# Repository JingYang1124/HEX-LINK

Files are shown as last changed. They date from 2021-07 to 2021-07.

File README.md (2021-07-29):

# HEX LINK - *A Distributed Somatosensory Interaction Device*  

#### 

#### 介绍
**HEX LINK**: **H**igher-order **EX**cess **LINK**

**这是一套可适用于PC端游戏的体感操作设备。**

Hex_Link+4

项目演示视频链接：  

[【开源·自制】真正的体感"只狼"_哔哩哔哩_bilibili](https://www.bilibili.com/video/BV1qy4y1M7Zw)

[【自制】"真 · 脚动档"极品飞车--程序员的健身日常_哔哩哔哩_bilibili](https://www.bilibili.com/video/BV1m54y1L7WU)

本仓库文件夹结构： 

```hxml
.
├─firmware # 软件（根据自己使用的工具选择如下一种工程即可）
│  ├─ArduinoIDE_Proj # Arduino IDE版工程 
│  │  ├─Additional_Libraries # 里面的文件夹需要复制到Arduino IDE安装目录下的libraries文件夹
│  │  ├─Hex_Link_Leonardo # 需要下载至接收端的程序
│  │  └─Hex_Link_Nano # 需要下载至发送端的程序
│  ├─Bootloaders # 需要下载至芯片的arduino bootloader 
│  └─Vscode_PlatformIO_Proj # VScode PlatformIO版工程 
│      ├─Hex_Link_Leonardo # 需要下载至接收端的程序
│      └─Hex_Link_Nano # 需要下载至发送端的程序
├─hardware # 硬件（PCB工程）
│  ├─BOM   # PCB的物料清单，包含参考的购买链接（链接仅作参考，在其他任何店铺购买相同型号即可）
│  ├─Hex_Link_Rec # 接收端PCB工程
│  ├─Hex_Link_Trans # 发送端PCB工程
│  └─Nano_Jtag_Pin # 转接板：用来烧录Nano bootloader的Jtag口转接板
├─model # 接收端外壳3维模型
│  ├─Solidworks_Project # 2018版本Solidworks工程
│  └─STL_TAP # STL文件，可直接用于3D打印.TAP文件是顶层亚克力板的CNC加工文件
├─references # 参考文档
└─tools # 额外的脚本工具
```

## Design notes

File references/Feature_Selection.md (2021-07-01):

# 基于信息增益的特征选取  

----------
> 如果数学公式无法正常显示，请下载至本地使用Typora打开或者在Chrome上安装Mathjax插件  
## 引言

**信息熵**，是一个数学上颇为抽象的概念，在这里不妨把信息熵理解成某种特定信息的出现概率。信息量度量的是一个具体事件发生了所带来的信息，而熵则是在结果出来之前对可能产生的信息量的期望。  
##### 信息熵公式：
$$H(X)=-\sum^{\infty}_{i=1}{p(x_i)\log_2(p(x_i))}$$

## 计算举例

现假设有测量了两种动作运动过程中的X轴加速度平均值  
  
动作A的X轴加速度平均值范围为A1至A3  
动作B的X轴加速度平均值范围为A2至A4

**首先计算样本的的信息熵**  
$$ H(X)=(-\frac{20}{40}\times\log_2(\frac{20}{40}))+(-\frac{20}{40}\times\log_2(\frac{20}{40}))=1$$  

以A2与A3为分界点将A1与A4上的数据分为3段  
分别计算每一段下的X的熵:  
$$ H(X|A\in[A_1,A_2))=-1\times\log_2(1)+0=0$$  
$$ H(X|A\in[A_2,A_3))=(-\frac{10}{20}\times\log_2(\frac{10}{20}))+(-\frac{10}{20}\times\log_2(\frac{10}{20}))=1$$  
$$ H(X|A\in[A_3,A_4])=-1\times\log_2(1)+0=0$$  
**条件熵**是一个X熵对A的期望
$$ H(X|A)=\frac{10}{40}\times H(X|A\in[A_1,A_2))+\frac{20}{40}\times H(X|A\in[A_2,A_3))+\frac{10}{40}\times H(X|A\in[A_3,A_4])=0.5$$  
**信息增益：**
$$g(X|A)=H(X)-H(X|A)=0.5$$

现假设如果我们也测量了两种运动过程中的Y轴加速度平均值  
其分布如下：  
  
**信息熵**  
$$ H(X)=(-\frac{20}{40}\times\log_2(\frac{20}{40}))+(-\frac{20}{40}\times\log_2(\frac{20}{40}))=1$$  

同样以A2与A3为分界点将A1与A4上的数据分为3段  
分别计算每一段下的X的熵:  
$$ H(X|A\in[A_1,A_2))=-1\times\log_2(1)+0=0$$  
$$ H(X|A\in[A_2,A_3))=(-\frac{6}{13}\times\log_2(\frac{6}{13}))+(-\frac{7}{13}\times\log_2(\frac{7}{13}))=1$$  
$$ H(X|A\in[A_3,A_4])=-1\times\log_2(1)+0=0$$  
**条件熵**是一个X熵对A的期望
$$ H(X|A)=\frac{14}{40}\times H(X|A\in[A_1,A_2))+\frac{6+7}{40}\times H(X|A\in[A_2,A_3))+\frac{13}{40}\times H(X|A\in[A_3,A_4])=0.324$$  
**信息增益：**
$$g(X|A)=H(X)-H(X|A)=0.676$$  
**<u>第二个特征（Y轴加速度）的信息增益比第一个特征（X轴加速度）的信息增益大，更适合做为区分A、B两种动作的特征。</u>**  

## 多个特征的组合  

> 很多时候，单独对每个特征进行信息增益计算后，选择信息增益最大的几个特征来进行识别也不一定能够获得更好的效果。这种时候，可以在计算信息增益时直接计算多个特征组合下的信息增益。

对于如下数据：  
  

>AcX:x轴加速度  AcY:y轴加速度  GyY：Y轴角速度  GyZ：Z轴角速度  

如果以单单一个特征计算其信息增益，结果为：  
$$g(X|AcY)>g(X|AcX)>g(X|GyZ)>g(X|GyY)$$  
似乎选择两个加速度值来判断三个类型最为合适。
那么我们将这两种特征画在一个XY平面上，同时作为比较也将两个角速度所组合而得到的平面点进行绘制：  
  
可以明显地看出，两个角速度所组成的特征能够将样本非常明显地划分为三类。  
实际上，如果我们想利用多个特征进行分类，在进行特征选择时，可以将多个特征在"空间”进行绘制，然后将“空间”划分为多个区域，之后根据每个区域中各类型出现的数量计算样本在这一组特征下的信息增益。  
例如我们分析AcX、AcY与GyY、GyZ两种特征时，可以将它们绘制在“2维平面上"，之后平面的横纵坐标都分成3份，把平面分成了9个区域， 

之后计算每个区域上样本的信息熵。

>若是有3个特征，就是在“3维空间”划分多个区域计算每个区域内样本的信息熵。  

下面是可用于计算多个特征组合下的信息增益的Python代码：  

```python
def Calculate_Multi_D_Entropy_Gain(Categories,Feature_Data,Seperate_Num):
    """
    Categories：
    [[1]
     [1]
     ...
     [2]
     ..
     [n]]
    Feature_Data:
    [[f1_1  f1_2]
     [f2_1  f2_2]
     [f3_1  f3_2]
     ...
     [fn_1  fn_2]] (two features)
    Seperate_Num:
    Separate feature data as (Seperate_Num)^(Feature_Num) parts
    """
    Feature_Shape = np.array(Feature_Data).shape
    """
    Feature_Shape[0]:how many data of one feature
    Feature_Shape[1]:how many features
    """
    Feature_Num = Feature_Shape[1]
    Segment_Length = 1/Seperate_Num
    Sample_Num = len(Categories)
    Categories_Num = max(Categories) 

    Total_Entropy = 0
     
    i = 1
    while(i <= Categories_Num):
        Total_Entropy += -1 * list(Categories).count(i)/Sample_Num * \
        math.log(list(Categories).count(i)/Sample_Num,2)
        i+=1
    print(Total_Entropy)
    """
    Condition_Entropy_Matrix:
    The numbers of different types in each Segment of feature zoom
    """
    Condition_Entropy_Matrix = np.zeros((int(Categories_Num), int(pow(Seperate_Num,Feature_Num))))
    for row in range(0,Sample_Num):
        Condition_Entropy_index = 0
        for col in range(0, Feature_Num):
            Condition_Entropy_index += pow(Seperate_Num,col) * \
            int(Feature_Data[row][col]/Segment_Length)
        Condition_Entropy_Matrix[int(Categories[row]) - 1][Condition_Entropy_index] += 1    
    print(Condition_Entropy_Matrix)    
    """
    e.g.: two-features Condition_Entropy_Matrix(Seperate_Num is 3):
       [[ 0 10 10  0  0  0  0  0  0 ]
        [ 0  0  0 20  0  0  0  0  0 ]
        [ 0  0  0  0  0  0 20  0  0 ]]
	No.   1  2  3  4  5  6  7  8  9  Segment
    """
    Condition_Entropy = 0
    for col in range(0, int(pow(Seperate_Num,Feature_Num))):
        Sample_Num_This_Seg = 0
        for row in range(0, int(Categories_Num)):
            Sample_Num_This_Seg += Condition_Entropy_Matrix[row][col]
        if Sample_Num_This_Seg != 0:
            for row in range(0, int(Categories_Num)):
                if Condition_Entropy_Matrix[row][col] != 0:
                    Condition_Entropy += -1 * (Sample_Num_This_Seg/Sample_Num) * \
                    Condition_Entropy_Matrix[row][col]/Sample_Num_This_Seg * \
                    math.log(Condition_Entropy_Matrix[row][col]/Sample_Num_This_Seg,2)
            
    print(Total_Entropy - Condition_Entropy)
    return Total_Entropy - Condition_Entropy
```

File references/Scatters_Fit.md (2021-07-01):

# 根据特征完成分类

----------
> 如果数学公式无法正常显示，请下载至本地使用Typora打开或者在Chrome上安装Mathjax插件  
## 引言

通过信息增益我们可以选择出最能够帮我们实现分类的特征。而知道了要用哪些特征之后，我们可以通过特征将各类样本划分在不同的区域并完成分类。  
例如对于如下三类样本点，使用GyY以及GyZ能够十分明显地将其划分为三类：  
  

## 椭圆拟合后进行类型的判断

对于上图的数据，我们可以找出3个椭圆，分别包含每一组样本。
  

我们把GyY作为x轴，GyZ作为y轴，则对于椭圆方程：  
$$ f(x,y)=\frac{[(x-x_0)\times\cos(\theta)+(y-y_0)\times\sin(\theta)]^2}{a^2}+\frac{[-(x-x_0)\times\sin(\theta)+(y-y_0)\times\cos(\theta)]^2}{b^2}=1$$  

  

> 其中(x0, y0）代表椭圆中心点的位置a、b为长短轴的半径,theta代表了中心旋转的角度  

**则f(GyY,GyZ)<1为椭圆内的点，f(GyY,GyZ)>1为椭圆外的点。**

## 利用OpenCV求出椭圆方程

利用OpenCV的cv2.fitEllipse() 函数可以帮我们快速地计算一组数据的椭圆拟合参数：  

```python
feature_data = np.array(feature_data).reshape(1,len(sample_num),1,feature_num)

for cnt in feature_data:
  ellipse = cv2.fitEllipse(cnt)
  print("The ellipse's parameters:")
  print(ellipse)
```

Print result：  

	The ellipse parameter:
	((81.27285766601562, 141.21487426757812), (6.844329833984375, 12.807960510253906), 109.20125579833984)  

> cv2.fitEllipse()返回值：ellipse = [ (x0, y0) , (2a, 2b), theta]  
> 注意，feature_data的shape需要是(1, 样本数量, 1, 特征数量)
> 例如5个样本，两个特征如下：  
>
> ```python
> [[[[ 82 146]]  
>   [[ 85 145]]  
>   [[ 82 143]]  
>   [[ 78 143]]  
>   [[ 80 143]]]]
> ```

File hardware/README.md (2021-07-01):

# HEX LINK hardware

#### 介绍

此文件夹中包含有HEX LINK的硬件电路的PCB工程文件。

其中：

Hex_Link_Rec为接收端电路

Hex_Link_Trans为发送端电路

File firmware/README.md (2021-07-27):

# HEX LINK firmware

#### 介绍
可以根据自己的工具选择其中一个类型的工程下载：

**ArduinoIDE_Proj**中的工程需要使用Arduino IDE打开。

> 优点：软件操作简便
>
> 缺点：文件结构没有Vscode工程清晰、无代码颜色提示、函数无法跳转等等
>
> ***注意：******Additional_Libraries文件夹下的所有文件夹需要拷贝到Arduino IDE安装目录下的Libraries文件夹中***

**Vscode_PlatformIO_Proj**中的工程需要使用安装了PlatformIO插件的Vscode打开。

> 优点：文件结构清晰、代码提示、代码补全、函数跳转提示等功能应有尽有。
>
> 缺点：需要安装Vscode以及PlatformIO插件
>
> ***安装Vscode以及PlatformIO可以参考：***
>
> [Arduino--VS Code开发Arduino PlatformIO IDE_似水流年-CSDN博客](https://liefyuan.blog.csdn.net/article/details/114917179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)

**Bootloaders**中的两个hex是需要分别下载接收端与发送端的芯片中。

> Leonardo_atmega32u4.hex需要下载至接收端的atmega32U4芯片中。熔丝位配置：低位值FF-高位值D8-拓展位值CB
>
> Nano_atmega328.hex需要下载至发送端的atmega328P芯片中。          熔丝位配置：低位值FF-高位值DA-拓展位值FD

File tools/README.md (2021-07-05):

# HEX LINK tools

#### 介绍

此文件夹中包含有制作过程中的辅助脚本工具

* Feature_Selection:特征选取脚本
* Scatters_Fit:椭圆拟合脚本
* Serial_Read:进行测试时，收集串口上的运动信息数据并保存的脚本

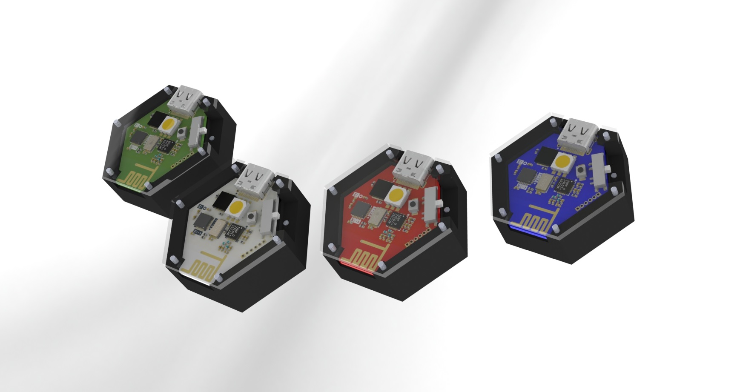
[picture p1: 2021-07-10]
pics/Hex_Link+4.jpg

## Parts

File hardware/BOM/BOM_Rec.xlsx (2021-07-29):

Comment | Description | Designator | Footprint | LibRef | Quantity | Where to buy(Just for reference) | Classfication
0.1uF | Capacitor | C1, C4 | CAP_0402 | 电容-0402 | 2 | https://m.tb.cn/h.4A1QYbn?sm=444077
10uF | 无极性电容 | C2, C6, C14 | CAP_0402 | CAP | 3 | https://m.tb.cn/h.4A1QYbn?sm=444077
20pF | 无极性电容 | C3, C5 | CAP_0402 | CAP | 2 | https://m.tb.cn/h.4A1QYbn?sm=444077
10nF | Capacitor | C7 | CAP_0402 | 电容-0402 | 1 | https://m.tb.cn/h.4A1QYbn?sm=444077
1uF | 无极性电容 | C8, C9, C10, C11, C12, C13, C15 | CAP_0402 | CAP | 7 | https://m.tb.cn/h.4A1QYbn?sm=444077
LED | LED | D1, D2, D3 | LED_0402_RED | LED_0402 | 3 | https://m.tb.cn/h.4A1OecR?sm=c25cbb
Header 3X2 | Header, 3-Pin, Dual row | J1 | HDR2X3 | Header 3X2 | 1 | https://m.tb.cn/h.4AyGDSU?sm=68925e
NRF24L01 |  | NRF | NRF24l01-SMD | NRF24L01 | 1 | https://m.tb.cn/h.4zegDgv?sm=8265cd
OLED_128X32 |  | OLED | OLED_128X32 | OLED_128X32 | 1 | https://m.tb.cn/h.4Aytr4q?sm=855d65 | 0.91寸 白色
2K |  | R1, R7, R10 | RES_0402 | RES | 3 | https://m.tb.cn/h.4A1QYbn?sm=444077
10k |  | R2, R3, R11, R13, R14 | RES_0402 | RES | 5 | https://m.tb.cn/h.4A1QYbn?sm=444077
22 |  | R8, R9 | RES_0402 | RES | 2 | https://m.tb.cn/h.4A1QYbn?sm=444077
390K |  | R12 | RES_0402 | RES | 1 | https://m.tb.cn/h.4A1QYbn?sm=444077
RST | Switch | RESET | SW_PB | SW-PB | 1 | https://m.tb.cn/h.4Bg5Wrk?sm=fd7e84
SWI | Switch | SWI_SP | SW_PB | SW-PB | 1 | https://m.tb.cn/h.4Bg5Wrk?sm=fd7e84
ATmega32U4-AU | 8-bit AVR Microcontroller, 2.7-5.5V, 32KB Flash, 2.5KB EEPROM, 1KB SRAM, USB Controller, 44-pin TQFP, Industrial Grade (-40癈 to 85癈) | U2 | 44ML_N | ATmega32U4-AU | 1 | https://m.tb.cn/h.4Bg9lg7?sm=868d90
LP2992 3V3 | LDO | U4 | SOT23-5 | LP2992 | 1 | https://m.tb.cn/h.4Ay8TdJ?sm=c470e7 | LP2992IM5X-3.3
USB-A |  | USB1 | USB_A/P_B | USB-A | 1 | https://m.tb.cn/h.4A1Lk3J?sm=e67d54 | 黑色胶贴片焊板公头
16MHz | 2脚无源脚晶振 | X1 | OSC 5032-2P | XTAL-2P | 1 | https://m.tb.cn/h.4A1VVXx?sm=62eb57 | 16M 2脚

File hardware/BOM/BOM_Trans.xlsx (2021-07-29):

Comment | Description | Designator | Footprint | LibRef | Quantity | Where to buy(Just for reference) | Classfication
1K | Resistor | BAT, R5, R6, R7, R10 | RES_0402 | RES, 电阻-0402 | 5 | https://m.tb.cn/h.4A1QYbn?sm=444077
0.1uF | 无极性电容, Capacitor | C1, C6, C11, C12, C18, C23 | CAP_0402 | CAP, 电容-0402 | 6 | https://m.tb.cn/h.4A1QYbn?sm=444077
10uF | 无极性电容 | C2, C4, C7 | CAP_0402 | CAP | 3 | https://m.tb.cn/h.4A1QYbn?sm=444077
20pF | 无极性电容 | C3, C5 | CAP_0402 | CAP | 2 | https://m.tb.cn/h.4A1QYbn?sm=444077
10nF | Capacitor, 无极性电容 | C8, C14, C15, C16 | CAP_0402 | 电容-0402, CAP | 4 | https://m.tb.cn/h.4A1QYbn?sm=444077
33nF | 无极性电容 | C13 | CAP_0402 | CAP | 1 | https://m.tb.cn/h.4A1QYbn?sm=444077
1.0pF | 无极性电容 | C17 | CAP_0402 | CAP | 1 | https://m.tb.cn/h.4A1QYbn?sm=444077
1.5pF | 无极性电容 | C19 | CAP_0402 | CAP | 1 | https://m.tb.cn/h.4A1QYbn?sm=444077
2.2nF | Capacitor, 无极性电容 | C20, C24 | CAP_0402 | 电容-0402, CAP | 2 | https://m.tb.cn/h.4A1QYbn?sm=444077
22pF | 无极性电容 | C21, C22 | CAP_0402 | CAP | 2 | https://m.tb.cn/h.4A1QYbn?sm=444077
4.7pF | 无极性电容 | C25 | CAP_0402 | CAP | 1 | https://m.tb.cn/h.4A1QYbn?sm=444077
LED | LED | D1, D2, D3 | LED_0402_RED | LED_0402 | 3 | https://m.tb.cn/h.4A1OecR?sm=c25cbb
LED-5050 | 3色LED | D4 | LED-5050W | LED-5050 | 1 | https://m.tb.cn/h.4BgVAp8?sm=e47aa9
RST | Switch | K_MODE | SW_PB | SW-PB | 1 | https://m.tb.cn/h.4Bg5Wrk?sm=fd7e84
3.9nH | INDUCTOR | L1 | 0402L_2 | INDUCTOR | 1 | https://m.tb.cn/h.4A1QYbn?sm=444077
8.2nH | INDUCTOR | L2 | 0402L_2 | INDUCTOR | 1 | https://m.tb.cn/h.4A1QYbn?sm=444077
2.7nH | INDUCTOR | L3 | 0402L_2 | INDUCTOR | 1 | https://m.tb.cn/h.4A1QYbn?sm=444077
NRF24L01P-R | NRF芯片 | NRF | QFN20 | NRF24L01P-R | 1 | https://m.tb.cn/h.4zegDgv?sm=8265cd
10K | Resistor | R1, R8 | RES_0402 | 电阻-0402 | 2 | https://m.tb.cn/h.4A1QYbn?sm=444077
2K | Resistor | R3 | RES_0402 | 电阻-0402 | 1 | https://m.tb.cn/h.4A1QYbn?sm=444077
200R | Resistor | R4 | RES_0402 | 电阻-0402 | 1 | https://m.tb.cn/h.4A1QYbn?sm=444077
22K | Resistor | R16 | RES_0402 | RES | 1 | https://m.tb.cn/h.4A1QYbn?sm=444077
0 | Resistor | R17 | RES_0402 | RES | 1 | https://m.tb.cn/h.4A1QYbn?sm=444077
2.2K | Resistor | R18, R19 | RES_0402 | RES | 2 | https://m.tb.cn/h.4A1QYbn?sm=444077
1M | Resistor | R20 | RES_0402 | RES | 1 | https://m.tb.cn/h.4A1QYbn?sm=444077
Header3_1.27mm | 1.27mm排针 | SPI_1, SPI_2 | HEADER3_1.27mm | Header3_1.27mm | 2 | https://m.tb.cn/h.4A1iQcn?sm=b88c8f
4Pin_sw | 3档开关 | SW1 | 4pin_SW | 4Pin_sw | 1 | https://m.tb.cn/h.4Ayka49?sm=ddadc3 | 拨动开关/三档8脚
CP2102 | USB转TTL | U1 | QFN-28 | CP2102 | 1 | https://m.tb.cn/h.4AykxKp?sm=bf1c97 | CP2102N-A02-GQFN28R
ATmega328P | 8-Bit AVR Microcontroller with 8K Bytes of In-System Programmable Flash Memory | U2 | 32A_N | ATmega8L-8AI | 1 | https://m.tb.cn/h.4zeWP9Y?sm=088797 | ATMEGA328P-AU 封装TQFP-32
MCP73833T-AMI/MF | Linear Charge Management Controller Li-Ion/Li-Pol 1mA 4.2V/4.35V/4.4V/4.5V 10-Pin DFN EP T/R | U3 | QFN_10_L | MCP73833T | 1 | https://m.tb.cn/h.4zeeHSZ?sm=613bf4
LP2992 3V3 | LDO | U4 | SOT23-5 | LP2992 | 1 | https://m.tb.cn/h.4Ay8TdJ?sm=c470e7 | LP2992IM5X-3.3
MPU6050 | 六轴传感器 | U5 | QFN-24 | MPU6050 | 1 | https://m.tb.cn/h.4A1UpwH?sm=449267
Type-C | Type-C插头 | USB1 | Type-C-TOP | USB-Type-C-TOP | 1 | https://m.tb.cn/h.4zeYV7n?sm=f41a36 | TYPE-C 16P 单排有孔 直插
16MHz | 2脚无源脚晶振 | X1, X2 | OSC 5032-2P | XTAL-2P | 2 | https://m.tb.cn/h.4A1VVXx?sm=62eb57 | 16M 2脚

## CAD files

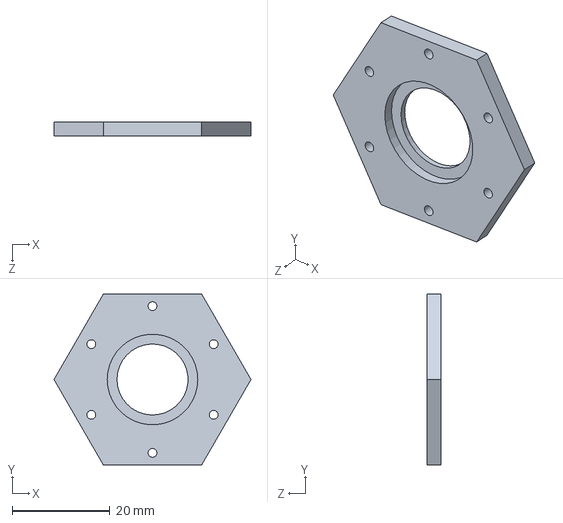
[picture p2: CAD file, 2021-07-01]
model/Solidworks_Project/Part2.SLDPRT
40.2 x 34.8 x 2.80 mm

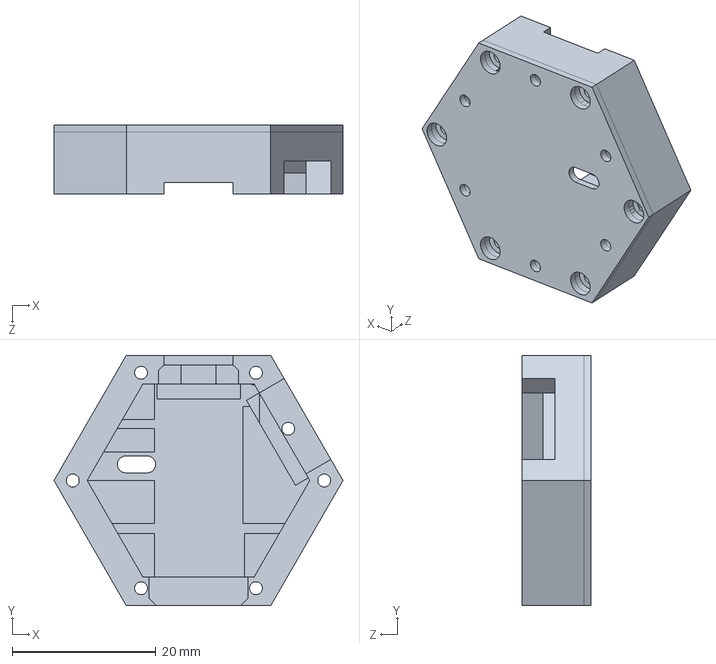
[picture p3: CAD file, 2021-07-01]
model/Solidworks_Project/Part1.SLDPRT
40.2 x 34.8 x 9.60 mm

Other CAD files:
model/STL_TAP/Part2.STL
model/STL_TAP/Part1.STL

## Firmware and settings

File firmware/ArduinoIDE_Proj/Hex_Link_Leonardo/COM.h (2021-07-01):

#ifndef COM_H
#define COM_H
#include "Universal_Headers.h"
#include <Mirf.h>
#include <nRF24L01.h>
#include <MirfHardwareSpiDriver.h>

#define MY_ADDRESS       "Leo"
#define TARGER_ADDRESS   "Nano"

#define NRF_CHANNEL      3

#define DEFAULT_DEVICEID 127
#define DEFAULT_COMMAND  1
#define DEFAULT_INDEX    1

/* CHEST COMMAND*/
#define CHEST_MID        2
#define CHEST_LEFT       3
#define CHEST_RIGHT      4
#define CHEST_JUMP       5

/* LEFT ARM COMMAND*/
#define LEFT_ARM_HOOK    2
#define LEFT_ARM_SEE_THROUGH     3
#define LEFT_ARM_CTRL    4
#define LEFT_ARM_SWITCH  5


/* RIGHT ARM COMMAND*/
#define RIGHT_ARM_ATTACK    2
#define RIGHT_ARM_DEFEND    3
#define RIGHT_ARM_TARGET    4
#define RIGHT_ARM_ATTACK_SP    5

/* LEFT LEG COMMAND*/
#define LEFT_LEG_STOP    2
#define LEFT_LEG_RUN     3
#define LEFT_LEG_WALK    4

/* TOOL COMMAND*/
#define TOOL_UNUSE       2
#define TOOL_USE         3

extern byte Devices_Last_Index[DeviceTypeNum];
extern CommandType R_Cmd,T_Cmd;
extern void NRF_Init(void);
extern void NRF_Send(CommandType * Tdata);
extern void NRF_Read(void);
#endif

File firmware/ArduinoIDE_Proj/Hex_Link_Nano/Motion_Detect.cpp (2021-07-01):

#include "Universal_Headers.h"
#include "IMU.h"
#include "COM.h"
#include "ISR.h"
#include "Motion_Detect.h"

uint8_t AcX_Max_Index_In_Array = 0;
uint8_t AcY_Max_Index_In_Array = 0;
uint8_t AcZ_Max_Index_In_Array = 0;
bool    Action_Found = false;
uint8_t Silent_Count = SILENT_VALVE;

#define LEFT_VALVE_ACX  131
#define RIGHT_VALVE_ACX 124
#define JUMP_VALVE_ACZ  130

const Ellipse_Para_Type Ctrl_Ellipse = {185,130,30,40,150};
const Ellipse_Para_Type Hook_Ellipse = {120,176,25,20,0};
const Ellipse_Para_Type Shift_Ellipse = {90,195,20,25,50};
const Ellipse_Para_Type Switch_Ellipse = {145,140,17,25,60};

const Ellipse_Para_Type Attack_Ellipse = {115,69,16,30,118};//x_0\y_0\a\b\Theta
const Ellipse_Para_Type Defend_Ellipse = {81,141,12,20,109};
const Ellipse_Para_Type Aim_Ellipse = {80,120,15,10,10};

#define WALK_VALVE  25
#define RUN_VALVE   14

#define TOOL_USE_VALVE    132
#define TOOL_UNUSE_VALVE  123
#define TOOL_CONTINUS_VALVE 5

#define ATTACK_SP_VALVE    139
#define ATTACK_SP_DEV_VALVE    2
#define ATTACK_SP_CONTINUS_VALVE 25


Std_ReturnType Fit_Ellipse(float x, float y, Ellipse_Para_Type * Elli_Para){
    Std_ReturnType Ret_Val = false;
    float Fit_Result = 0;
    Fit_Result = (pow(((x-Elli_Para->x_0)*cos(Elli_Para->Theta/180*3.14159) + (y-Elli_Para->y_0)*sin(Elli_Para->Theta/180*3.14159)),2)/pow((Elli_Para->a),2)
      +
      pow((-1*(x-Elli_Para->x_0)*sin(Elli_Para->Theta/180*3.14159) + (y-Elli_Para->y_0)*cos(Elli_Para->Theta/180*3.14159)),2)/pow((Elli_Para->a),2));
    
    if(Fit_Result<=1){
        Ret_Val = true; 
        Serial.println(Fit_Result);
      }
     return Ret_Val;
}

void Prv_Max_Data(IMU_AcData_Type * OutAcData,IMU_GyData_Type * OutGyData){
  uint8_t temVal_x;
  uint8_t temVal_y;
  uint8_t temVal_z;
  temVal_x = 0;temVal_y = 0;temVal_y = 0;
  for(uint8_t index = 0; index < IMU_DATA_BATCH;index ++){
    if(Prv_AcData[index].AcX > temVal_x)temVal_x = Prv_AcData[index].AcX;
    if(Prv_AcData[index].AcY > temVal_y)temVal_y = Prv_AcData[index].AcY;
    if(Prv_AcData[index].AcZ > temVal_z)temVal_z = Prv_AcData[index].AcZ;
  }
  OutAcData->AcX = temVal_x;OutAcData->AcY = temVal_y;OutAcData->AcZ = temVal_z;
  temVal_x = 0;temVal_y = 0;temVal_y = 0;
  for(uint8_t index = 0; index < IMU_DATA_BATCH;index ++){
    if(Prv_GyData[index].GyX > temVal_x)temVal_x = Prv_GyData[index].GyX;
    if(Prv_GyData[index].GyY > temVal_y)temVal_y = Prv_GyData[index].GyY;
    if(Prv_GyData[index].GyZ > temVal_z)temVal_z = Prv_GyData[index].GyZ;
  }
  OutGyData->GyX = temVal_x;OutGyData->GyY = temVal_y;OutGyData->GyZ = temVal_z;
}

void Prv_Min_Data(IMU_AcData_Type * OutAcData,IMU_GyData_Type * OutGyData){
  uint8_t temVal_x;
  uint8_t temVal_y;
  uint8_t temVal_z;
  temVal_x = 255;temVal_y = 255;temVal_y = 255;
  for(uint8_t index = 0; index < IMU_DATA_BATCH;index ++){
    if(Prv_AcData[index].AcX < temVal_x)temVal_x = Prv_AcData[index].AcX;
    if(Prv_AcData[index].AcY < temVal_y)temVal_y = Prv_AcData[index].AcY;
    if(Prv_AcData[index].AcZ < temVal_z)temVal_z = Prv_AcData[index].AcZ;
  }
  OutAcData->AcX = temVal_x;OutAcData->AcY = temVal_y;OutAcData->AcZ = temVal_z;
  temVal_x = 0;temVal_y = 0;temVal_y = 0;
  for(uint8_t index = 0; index < IMU_DATA_BATCH;index ++){
    if(Prv_GyData[index].GyX < temVal_x)temVal_x = Prv_GyData[index].GyX;
    if(Prv_GyData[index].GyY < temVal_y)temVal_y = Prv_GyData[index].GyY;
    if(Prv_GyData[index].GyZ < temVal_z)temVal_z = Prv_GyData[index].GyZ;
  }
  OutGyData->GyX = temVal_x;OutGyData->GyY = temVal_y;OutGyData->GyZ = temVal_z;
}

void Prv_Ave_Data(IMU_AcData_Type * OutAcData,IMU_GyData_Type * OutGyData){
  int16_t AcX_Sum = 0;
  int16_t AcY_Sum = 0;
  int16_t AcZ_Sum = 0;
  int16_t GyX_Sum = 0;
  int16_t GyY_Sum = 0;
  int16_t GyZ_Sum = 0; 
  for(uint8_t index = 0; index < IMU_DATA_BATCH;index ++){
    AcX_Sum += Prv_AcData[index].AcX;
    AcY_Sum += Prv_AcData[index].AcY;
    AcZ_Sum += Prv_AcData[index].AcZ;
    GyX_Sum += Prv_GyData[index].GyX;
    GyY_Sum += Prv_GyData[index].GyY;
    GyZ_Sum += Prv_GyData[index].GyZ;
  }
  OutAcData->AcX = AcX_Sum/IMU_DATA_BATCH;
  OutAcData->AcY = AcY_Sum/IMU_DATA_BATCH;
  OutAcData->AcZ = AcZ_Sum/IMU_DATA_BATCH;
  OutGyData->GyX = GyX_Sum/IMU_DATA_BATCH;
  OutGyData->GyY = GyY_Sum/IMU_DATA_BATCH;
  OutGyData->GyZ = GyZ_Sum/IMU_DATA_BATCH;
}
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
